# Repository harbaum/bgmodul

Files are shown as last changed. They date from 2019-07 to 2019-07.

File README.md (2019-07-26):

# BG-Modul

Unterlagen zum Produkt-Modul am Bismarck-Gymnasium.

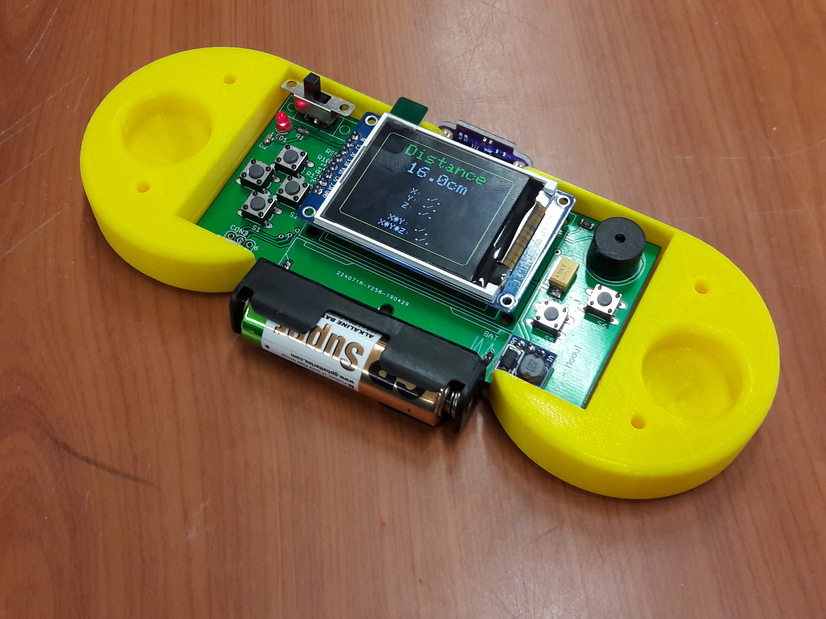
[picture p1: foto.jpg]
BG-Modul Foto


Dieses Repository enthält die Schaltpläne und Platinenunterlagen
als PDF und im Original-Eagle-Format. Die Dateien können mit der
Test-Version von Eagle geöffnet werden.

Das Demo-Program bgmeter.ino kann in der Arduino-IDE geöffnet
werden. Es benötigt als zusätzliche Bibliotheken

  - ```VL53L0X distance sensor library``` von Pololu für den Laser-Sensor
  - ```TFT_ST7735 library``` von Bodmer für das Display

In der Datei ```User_Setup.h``` der TFT_ST7735-Bibliothek müssen
folgenden Zeilen angepasst werden, damit korrekt eingestellt ist an
welchen Anschlüssen des Prozessors das Display angeschlossen ist:

```
// ###### EDIT THE PIN NUMBERS IN THE 3 LINES FOLLOWING TO SUIT YOUR SETUP ######

#define TFT_CS  10  // Chip select control pin
#define TFT_DC  8  // Data Command control pin
#define TFT_RST 9  // Reset pin (could connect to Arduino RESET pin)
```

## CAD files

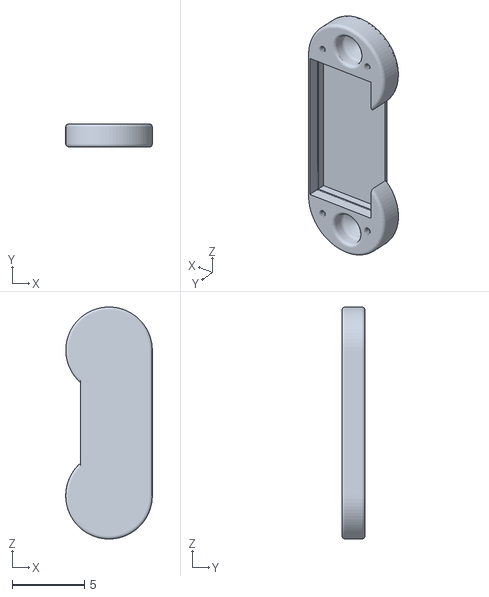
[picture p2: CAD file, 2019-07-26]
case_bottom.stl
6.00 x 1.58 x 16.1

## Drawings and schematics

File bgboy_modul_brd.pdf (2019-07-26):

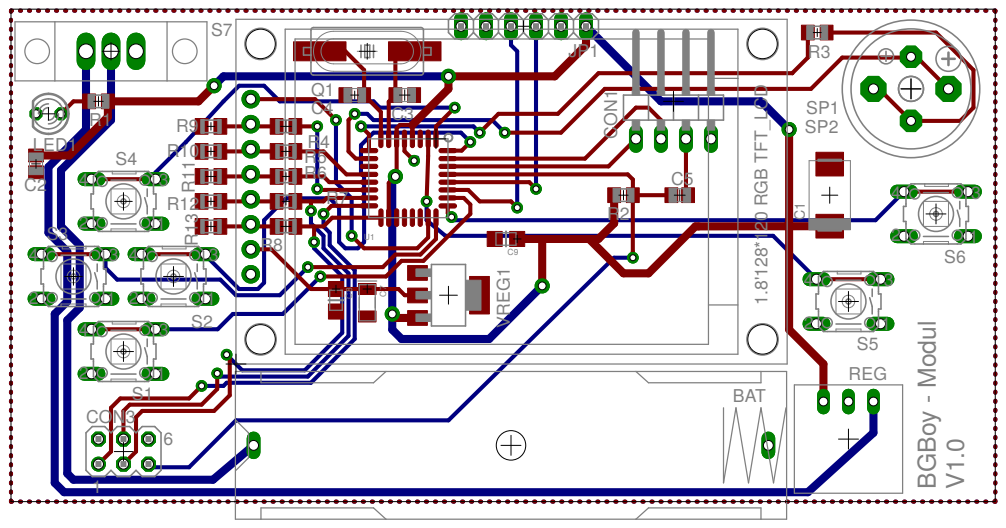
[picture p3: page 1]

BGBoy - Modul V1.0 1.8'128*120 RGB TFT_LCD 1 6 2 1 4 3 2 1 4 3 2 1 4 3 2 1 4 32 1 4 3 2 1 4 3 C2 C1 LED1 Q1 C C3 4 R1 R2 S2 S3 S4 S5 S6 S1 SP1 R3 BAT REG CON1 C5 SP2 S7 JP1 C7 VREG1 C8 C9 R4 R5 R6R7 R8 R9 R10R11 R12R13 CON3 U1

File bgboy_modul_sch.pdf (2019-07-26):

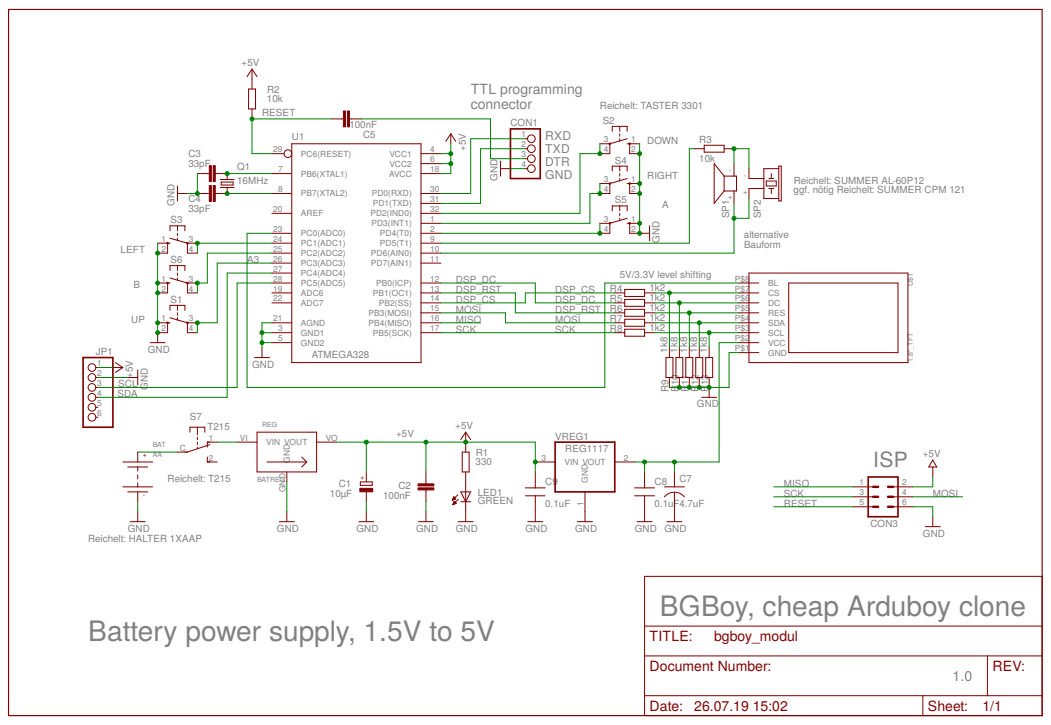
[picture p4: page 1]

Reichelt: SUMMER AL-60P12
ggf. nötig Reichelt: SUMMER CPM 121

Battery power supply, 1.5V to 5V

Document Number: 1.0 | REV:

Date: 26.07.19 15:02 | Sheet: 1/1

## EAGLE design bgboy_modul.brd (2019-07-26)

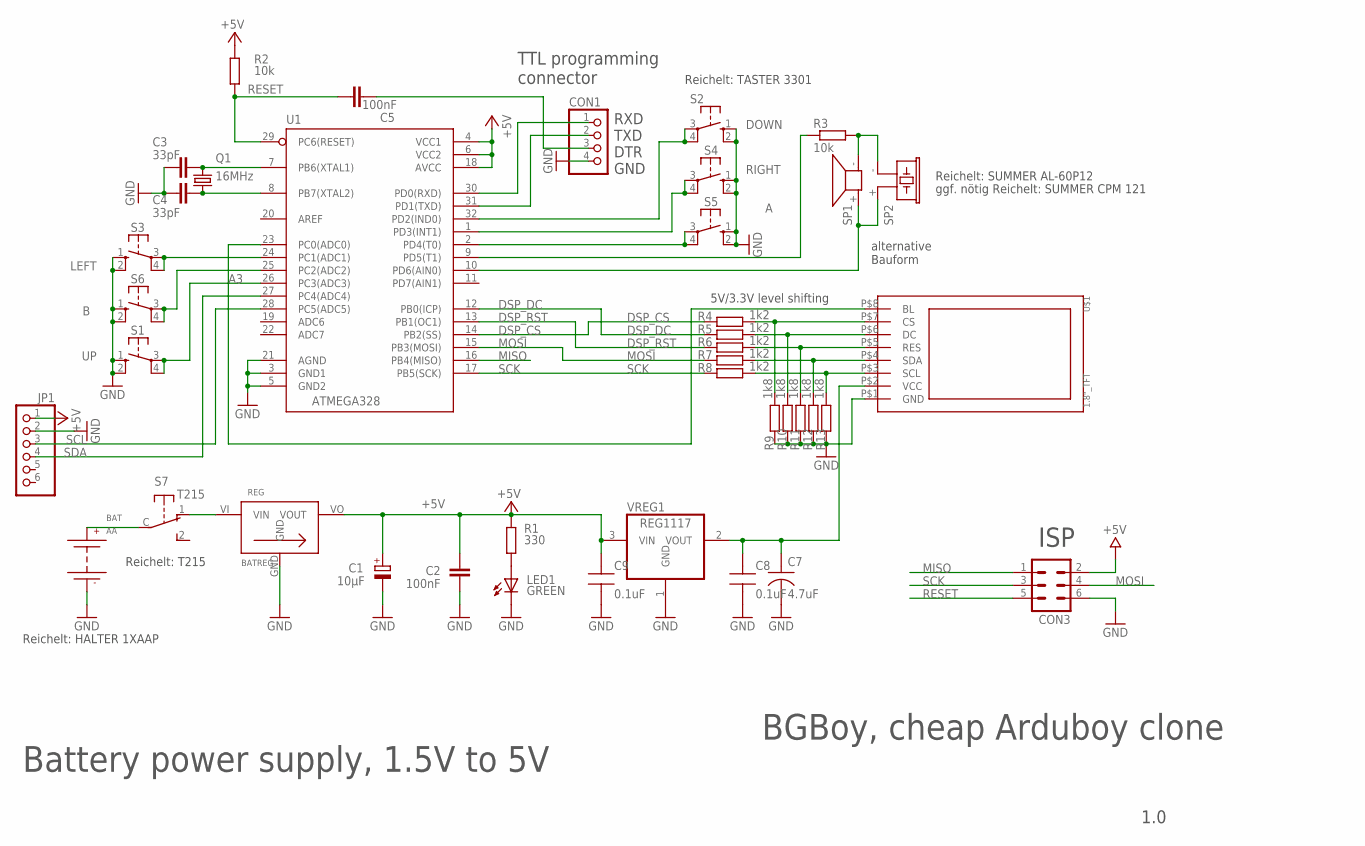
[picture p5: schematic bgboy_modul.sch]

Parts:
BAT: AA; 1XAAP
C1: 10µF; SMC_D
C2, C5: 100nF; C0805
C3, C4: 33pF; C0805
C7: 4.7uF; TAN-A
C8, C9: 0.1uF; CAP0805-NP
CON1: PINHD-1X4/90; 1X04/90
CON3: MA03-2
JP1: PINHD-1X6; 1X06
LED1: GREEN; LED3MM
Q1: 16MHz; HC49UP
R1: 330; R0805
R2, R3: 10k; R0805
R4, R5, R6, R7, R8: 1k2; M0805
R9, R10, R11, R12, R13: 1k8; M0805
REG: BATREG
S1: UP; B3F-10XX
S2: DOWN; B3F-10XX
S3: LEFT; B3F-10XX
S4: RIGHT; B3F-10XX
S5: A; B3F-10XX
S6: B; B3F-10XX
S7: T215
SP1: KSS1201
SP2: F/CM12P
U1: ATMEGA328; QFP032
U$1: 1.8"_TFT
VREG1: REG1117; SOT223

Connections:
+5V: C1.+, C2.2, C9.1, JP1.1, R1.1, R2.2, REG.VO (VOUT), U1.4 (VCC1), U1.6 (VCC2), U1.18 (AVCC), VREG1.3 (VIN)
A0: U1.23 (PC0(ADC0)), U$1.P$8 (BL)
A1: S3.3, S3.4 (P1), U1.24 (PC1(ADC1))
A2: S6.3, S6.4 (P1), U1.25 (PC2(ADC2))
A3: S1.3, S1.4 (P1), U1.26 (PC3(ADC3))
D0: CON1.1, U1.30 (PD0(RXD))
D1: CON1.2, U1.31 (PD1(TXD))
D2: S2.3, S2.4 (P1), U1.32 (PD2(IND0))
D3: S4.3, S4.4 (P1), U1.1 (PD3(INT1))
D4: S5.3, S5.4 (P1), U1.2 (PD4(T0))
D5: R3.1, U1.9 (PD5(T1))
D7: SP1.+ (1), SP2.+ (1), U1.10 (PD6(AIN0))
DSP_CS: R4.1, U1.14 (PB2(SS))
DSP_DC: R5.1, U1.12 (PB0(ICP))
DSP_RST: R6.1, U1.13 (PB1(OC1))
GND: BAT.-, C1.-, C2.1, C3.1, C4.1, C7.2, C8.2, C9.2, CON1.4, CON3.6, JP1.2, LED1.K (C), R9.1, R10.1, R11.1, R12.1, R13.1, REG.GND, S1.1 (S), S1.2 (S1), S2.1 (S), S2.2 (S1), S3.1 (S), S3.2 (S1), S4.1 (S), S4.2 (S1), S5.1 (S), S5.2 (S1), S6.1 (S), S6.2 (S1), U1.3 (GND1), U1.5 (GND2), U1.21 (AGND), U$1.P$1 (GND), VREG1.1 (GND)
MISO: CON3.1, U1.16 (PB4(MISO))
MOSI: CON3.4, R7.1, U1.15 (PB3(MOSI))
unnamed: C4.2, Q1.1, U1.8 (PB7(XTAL2))
unnamed: C3.2, Q1.2, U1.7 (PB6(XTAL1))
unnamed: LED1.A, R1.2
unnamed: REG.VI (VIN), S7.1 (O)
unnamed: BAT.+, S7.C
unnamed: R4.2, R9.2, U$1.P$7 (CS)
unnamed: R6.2, R11.2, U$1.P$5 (RES)
unnamed: R3.2, SP1.- (2), SP2.- (2)
unnamed: R5.2, R10.2, U$1.P$6 (DC)
unnamed: C5.2, CON1.3
unnamed: C7.1, C8.1, U$1.P$2 (VCC), VREG1.2 (VOUT)
unnamed: R7.2, R12.2, U$1.P$4 (SDA)
unnamed: R8.2, R13.2, U$1.P$3 (SCL)
RESET: C5.1, CON3.5, R2.1, U1.29 (PC6(RESET))
SCK: CON3.3, R8.1, U1.17 (PB5(SCK))
SCL: JP1.3, U1.28 (PC5(ADC5))
SDA: JP1.4, U1.27 (PC4(ADC4))
VCC: CON3.2

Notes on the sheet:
Reichelt: T215
Reichelt: HALTER 1XAAP
ggf. nötig Reichelt: SUMMER CPM 121
Reichelt: SUMMER AL-60P12
Reichelt: TASTER 3301
Battery power supply, 1.5V to 5V
TTL programming connector
BGBoy, cheap Arduboy clone
1.0
RXD TXD DTR GND
alternative Bauform
5V/3.3V level shifting
ISP

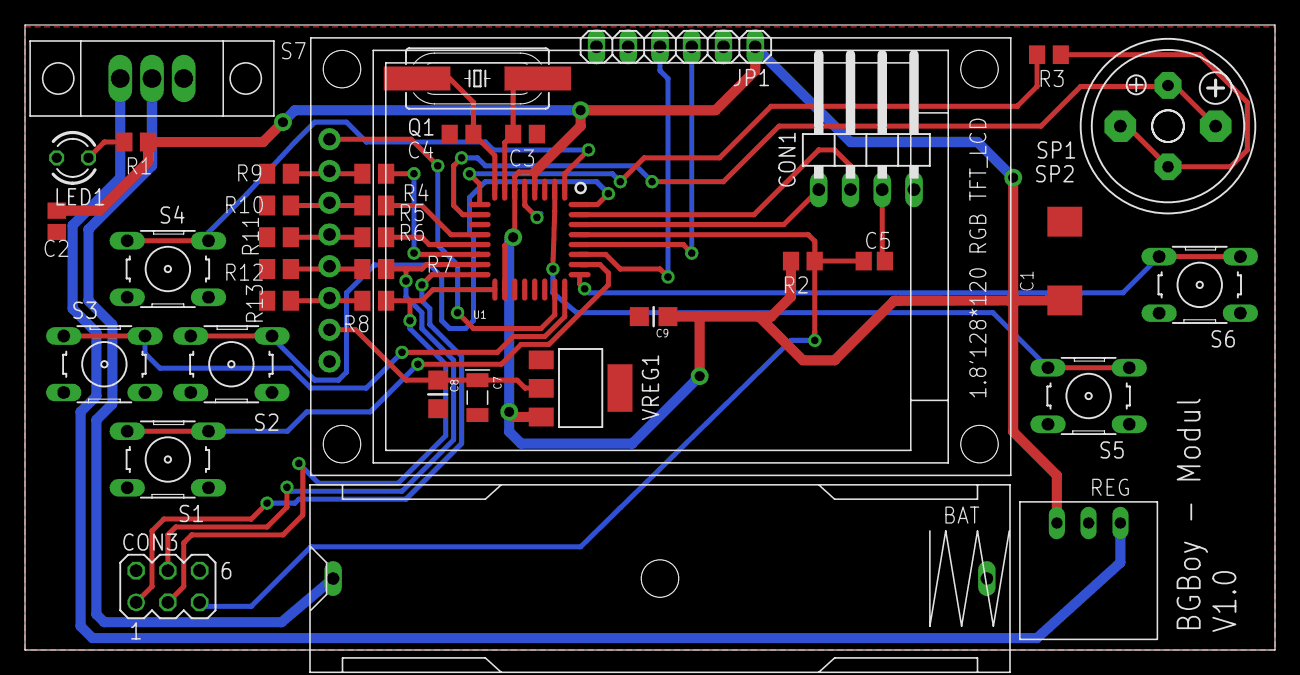
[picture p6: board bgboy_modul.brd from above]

Board: 2 copper layers, 100.0 x 50.0 mm, 40 parts (0 on the bottom side), 35 nets.

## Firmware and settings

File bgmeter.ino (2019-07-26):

#define ST7735
#define POLOLU    // define this to use pololu library which saves flash memory
// #define LONG_RANGE

#ifdef POLOLU
#include <Wire.h>
#include <VL53L0X.h>
VL53L0X sensor;
#else
#include <Adafruit_VL53L0X.h>
Adafruit_VL53L0X lox = Adafruit_VL53L0X();
#endif

#ifdef ST7735
#include <TFT_ST7735.h> 
TFT_ST7735 tft = TFT_ST7735();       // Invoke custom library
#define BLACK   TFT_BLACK
#define WHITE   TFT_WHITE
#define YELLOW  TFT_YELLOW
#define GREEN   TFT_GREEN
#else
#include <Adafruit_ST7735.h> // Hardware-specific library for ST7735
#define TFT_CS        10 
#define TFT_RST        9
#define TFT_DC         8
Adafruit_ST7735 tft = Adafruit_ST7735(TFT_CS, TFT_DC, TFT_RST);
#define BLACK   ST77XX_BLACK
#define WHITE   ST77XX_WHITE
#define YELLOW  ST77XX_YELLOW
#define GREEN   ST77XX_GREEN
#endif

#define UP     3
#define RIGHT  2
#define DOWN  17

#define TITLE "Distance"


void distance_str(char *str, int32_t val) {
  // 64-(tmp_str.length()*12)/2

  if(val < 0) {
    strcpy(str, "./.");
    return;
  }

  // convert integer to string
  ltoa(val, str, 10);

  // move last digit one positon back and insert decimal dot
  char l = strlen(str);
  str[l+1] = 0;         // termination char
  str[l] = str[l-1];    // move digit
  str[l-1] = '.';       // set dot

  // append "cm"
  strcpy(str+l+1, "cm"); 
}

void draw_centered(char y, char *str) {
  
  // erase previous text area
  tft.fillRect(10, y, 140, 8, BLACK);

  tft.setCursor(80-(6*strlen(str))/2, y);
  tft.setTextSize(0);
  tft.setTextColor(WHITE, BLACK);
  tft.setTextWrap(false);
  
  tft.print(str);  
}

void draw_mem(char y, int16_t val) {
  int yd[] = { 60, 70, 80 };
  char str[32];

  strcpy(str, "X: ");
  str[0] += y;
  distance_str(str+strlen(str), val);

  draw_centered(yd[y], str);
}

void draw_square(int32_t val) {
  char str[32];

  strcpy(str, "X*Y: ");
  distance_str(str+strlen(str), val);
  if(val >= 0) strcat(str, "^2");
  draw_centered(100, str);
}

void draw_cube(int32_t val) {
  char str[32];

  strcpy(str, "X*Y*Z: ");
  distance_str(str+strlen(str), val);
  if(val >= 0) strcat(str, "^3");
  draw_centered(110, str);
}

void setup(void) { 
#ifdef POLOLU
  Wire.begin();
  sensor.init();
  sensor.setTimeout(500);

#ifdef LONG_RANGE
  // ---- enable long range mode, increases sensivity and work better in dark environments ----
  // lower the return signal rate limit (default is 0.25 MCPS)
  sensor.setSignalRateLimit(0.1);
  // increase laser pulse periods (defaults are 14 and 10 PCLKs)
  sensor.setVcselPulsePeriod(VL53L0X::VcselPeriodPreRange, 18);
  sensor.setVcselPulsePeriod(VL53L0X::VcselPeriodFinalRange, 14);
#endif
#else
  lox.begin();
#endif
  
#ifdef ST7735
  tft.init();
#else
  tft.initR(INITR_REDTAB); // Init ST7735R chip, green tab
#endif

  tft.setRotation(1);
  
  // clear screen
  tft.fillScreen(BLACK);

  // setup screen mask
  tft.drawRoundRect(5, 5, 150, 118, 5, YELLOW);
  tft.setCursor(80-(strlen(TITLE)*12)/2, 10);
  tft.setTextSize(2);
  tft.setTextColor(GREEN, BLACK);
  tft.setTextWrap(false);
  tft.print(TITLE); 

  draw_mem(0, -1);
  draw_mem(1, -1);
  draw_mem(2, -1);
  draw_square(-1);
  draw_cube(-1);

  // configure UP/RIGHT/DOWN buttons as inputs
  pinMode(UP, INPUT_PULLUP);
  pinMode(RIGHT, INPUT_PULLUP);
  pinMode(DOWN, INPUT_PULLUP);
}

void draw_distance(int16_t val) {
  static int16_t cval = -1;  
  char str[32];

  if(cval == val) 
    return;

  cval = val;

  // draw main distance 
  if(val < 0) strcpy(str, "out of range");
  else        distance_str(str, val);
  
  // erase previous text area
  tft.fillRect(6, 30, 148, 16, BLACK);

  tft.setCursor(80-(12*strlen(str))/2, 30);
  tft.setTextSize(2);
  tft.setTextColor(WHITE, BLACK);
  tft.setTextWrap(false);
  
  tft.print(str);
}

void loop() {
  static int16_t x=-1,y=-1,z=-1;
  
#ifdef POLOLU
  int16_t distance = sensor.readRangeSingleMillimeters();
  if(sensor.timeoutOccurred())
    distance = -1;
#else
  VL53L0X_RangingMeasurementData_t measure;
  lox.rangingTest(&measure, false); // pass in 'true' to get debug data printout!
  int16_t distance = measure.RangeMilliMeter;
  if(measure.RangeStatus == 4)
    distance = -1;
#endif

  draw_distance(distance);
  
  if(!digitalRead(UP)) {
     x = distance;
     draw_mem(0, x);

     if(y >= 0)
        draw_square((int32_t)x*(int32_t)y);
     if((y >= 0) && (z >= 0))
        draw_cube((int32_t)x*(int32_t)y*(int32_t)z);
  }
  
  if(!digitalRead(RIGHT)) {
     y = distance;
     draw_mem(1, y);
     
     if(x >= 0)
        draw_square((int32_t)x*(int32_t)y);
     if((x >= 0) && (z >= 0))
        draw_cube((int32_t)x*(int32_t)y*(int32_t)z);
  }

  if(!digitalRead(DOWN)) {
     z = distance;
     draw_mem(2, z);
     if((x >= 0) && (y >= 0))
        draw_cube((int32_t)x*(int32_t)y*(int32_t)z);
  }
  
  delay(100);
}
